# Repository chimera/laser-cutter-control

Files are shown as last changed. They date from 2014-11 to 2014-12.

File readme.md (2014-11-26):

# Chimera Laser Cutter Control

**Responsible Adult**: [Randy Hall](https://github.com/randybuildsthings)

This Chimera project provides the project (circuit board, bill of materials, etc.) to provide a Mach3/LinuxCNC capable controller board to drive the laser + the stepper motors that position the cutting beam.

This project borrows *heavily* (read: hours of looking over a PDF schematic) of the very excellent but out-of-stock Laser Cutter Converter board that Chris Jones of [Chris' Circuits](http://www.chriscircuits.com) successfully made and then sold out of repeatedly thanks to Hack-A-Day in 2013.

Well, it's almost 2015 and he doesn't seem to be making it any more. Enter the Chimera!

## Ew, EAGLE CAD

Yeah, it's EAGLE CAD. This design works entirely in their free tier, using just two layers and within the size constraints. We might consider moving it to KiCAD or another PCB layout tool, but for now, it's this.

This project was built from scratch using EAGLE CAD 7. We don't expect that it will work on previous version of the program.

## But, what do I do with this?

Ultimately, we will provide packaged and tagged releases of the Gerber and Excellon files for a given revision. Then you can take those files to your favorite PCB fab and get them made.

For now, you can load up whatever version of EAGLE CAD you can find, and open the `.SCH` and `.BRD` files into the software. Behold! The masterpiece. Now you can use the CAM batch tool to create the Gerber and Excellon files.

Step three... PROFIT!

## Warranty

*There is none.*

If you build and use this board and it burns down your laser cutter, your house, your RV, your office building, or the whole neighborhood, **it's on you bro.** If you don't accept this, then don't use this design. Otherwise, experiment wisely and always have a fire extinguisher handy. And an emergency power shutoff wouldn't hurt either.

The good news is we've now open sourced it, so knock yourself out! (*Note: any reference to knocking oneself out is said here only in jest, and neither Chimera Art Space or the author take any responsibility for anyone who actually takes the imperative literally, thereby effecting blunt force trauma on themselves causing loss of consciousness. This message will self-destruct whenever we get around to editing the Markdown to remove it*)

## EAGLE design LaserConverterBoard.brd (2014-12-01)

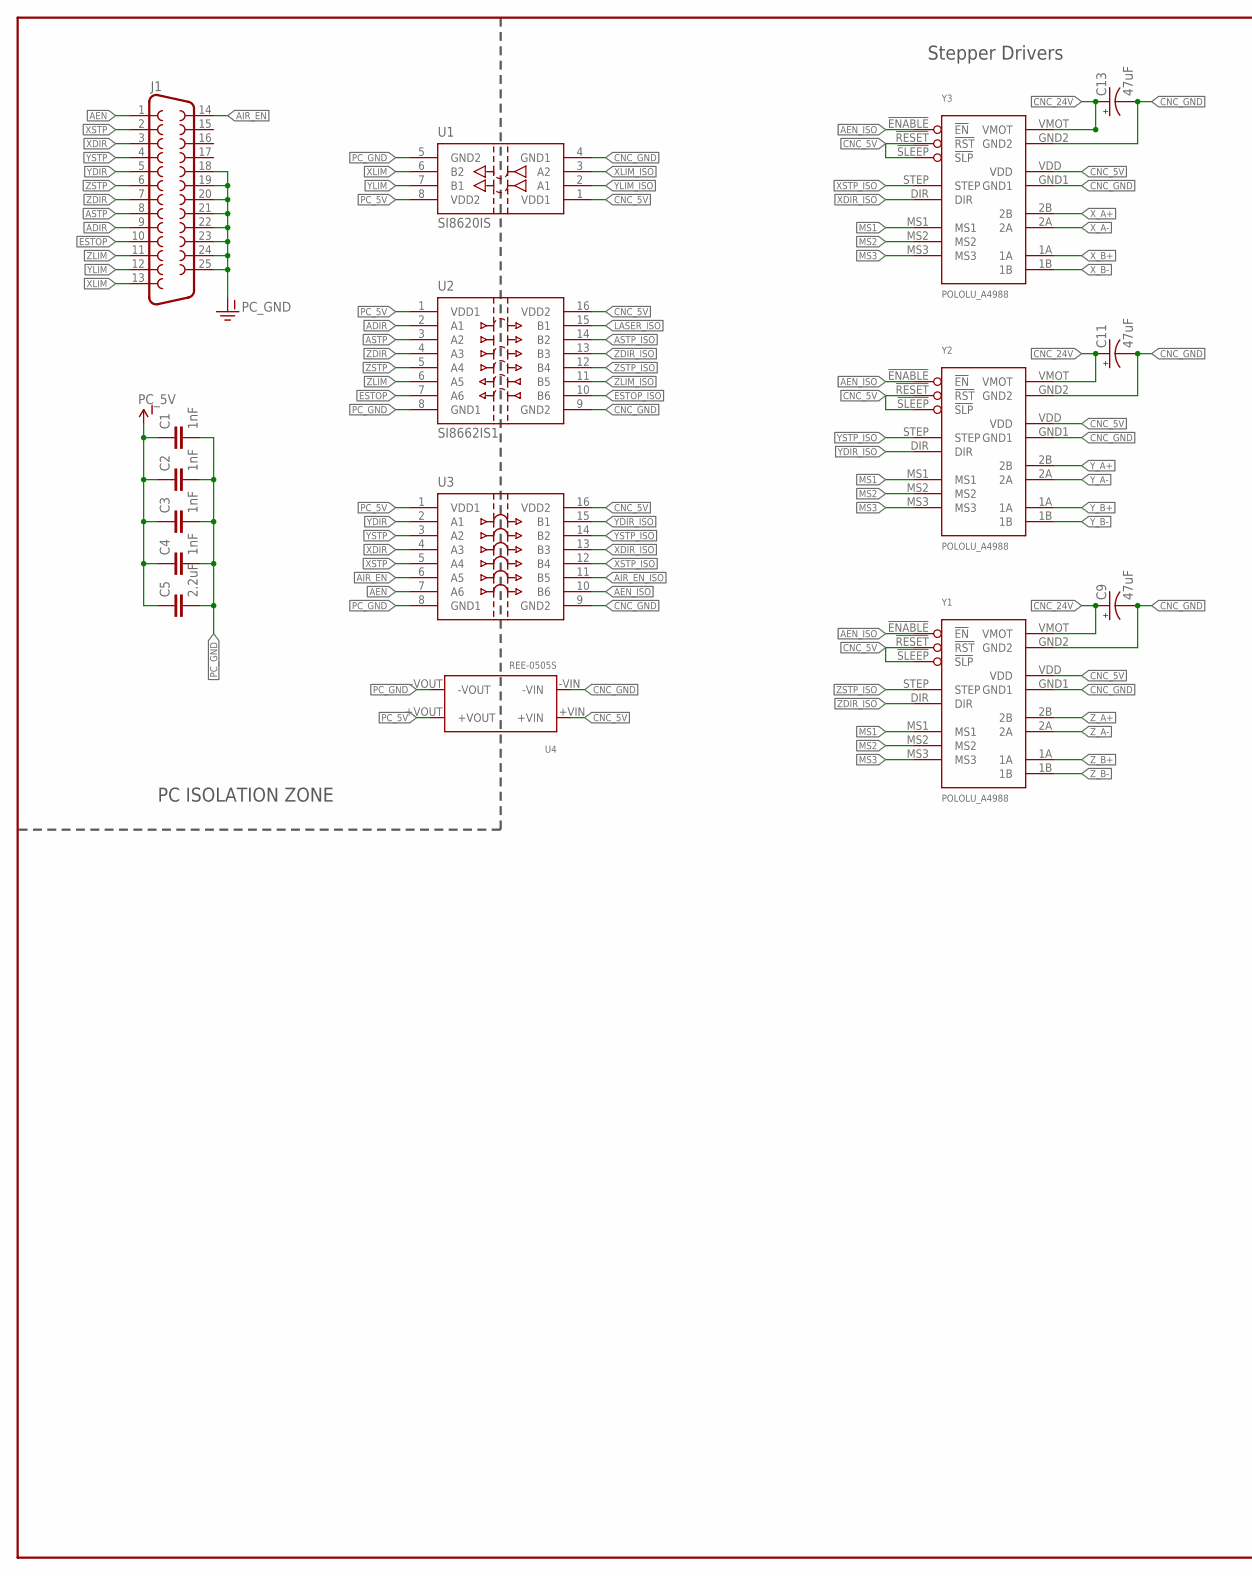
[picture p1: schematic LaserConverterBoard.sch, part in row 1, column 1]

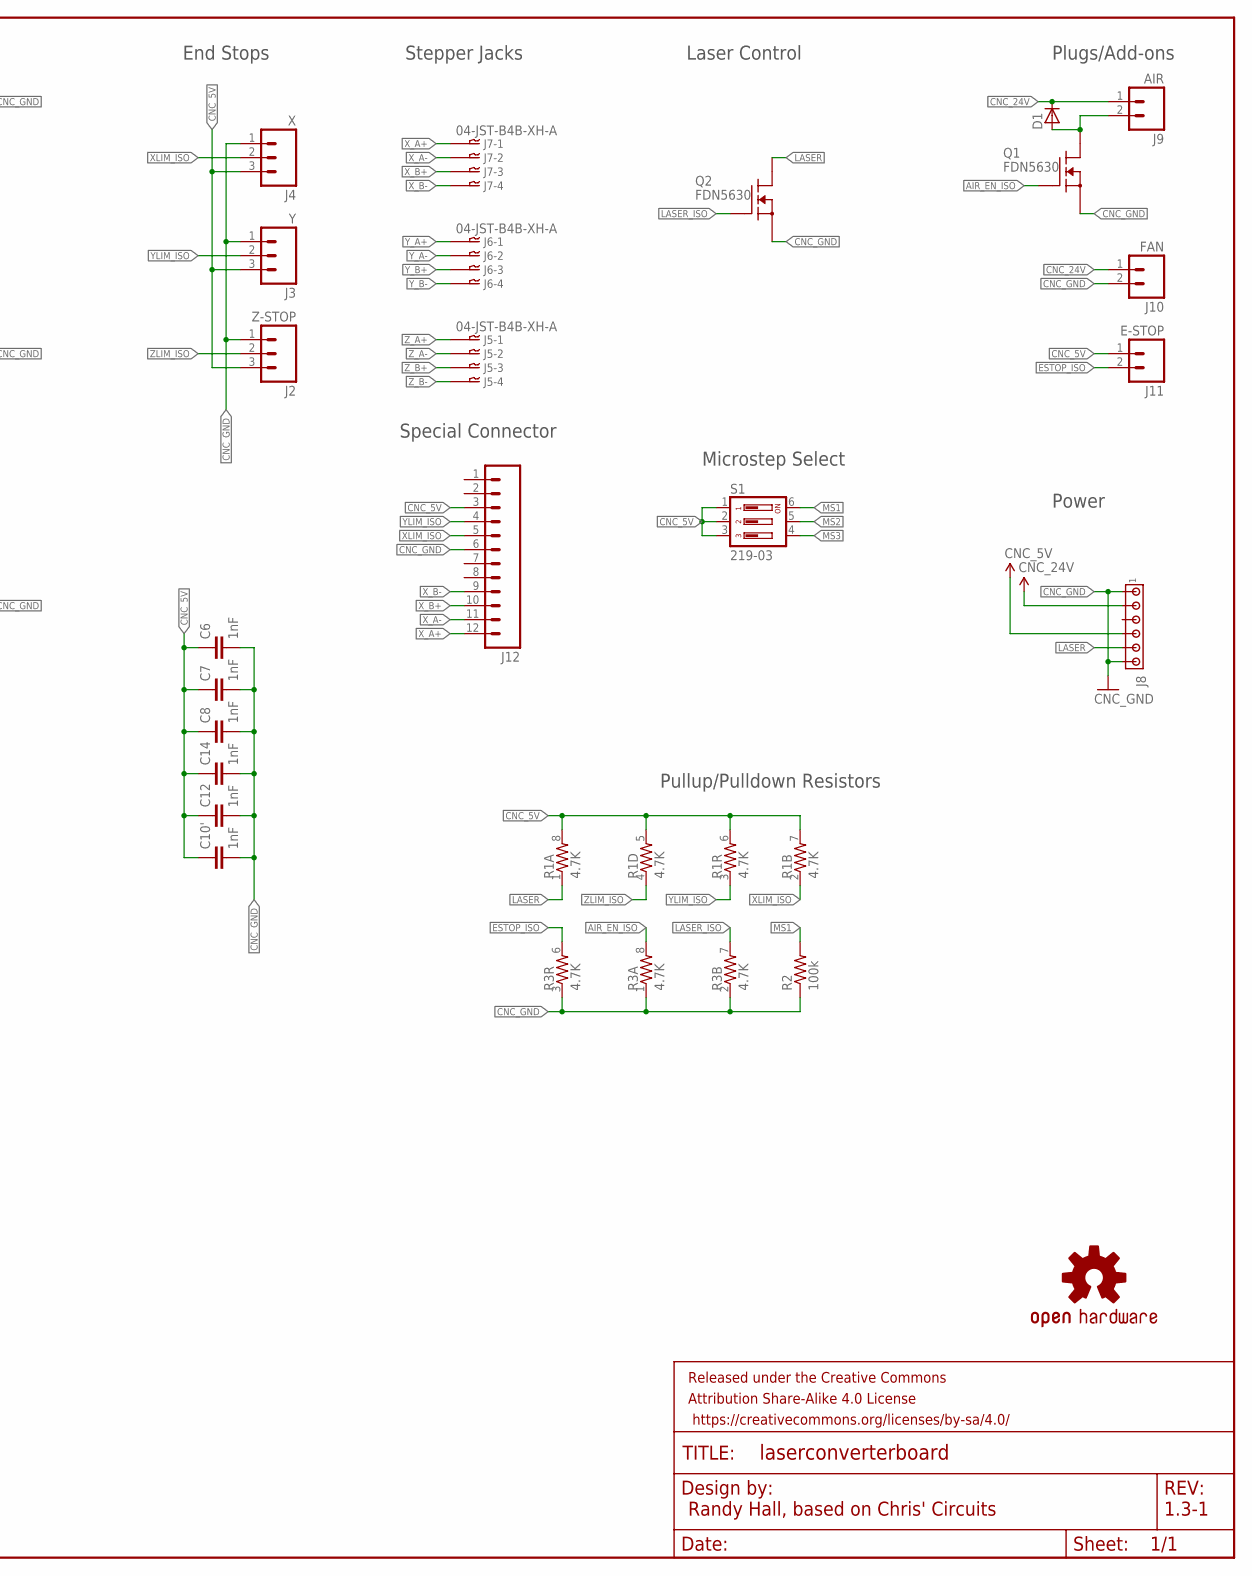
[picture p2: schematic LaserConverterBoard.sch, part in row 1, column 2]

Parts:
C1, C2, C3, C4, C6, C7, C8, C10', C12, C14: 1nF; 0603-CAP
C5: 2.2uF; 0603-CAP
C9, C11, C13: 47uF; PANASONIC_E
D1: D-SOD123; SOD123
FRAME1: FRAME-LEDGER; CREATIVE_COMMONS
J1: F25HP
J2: Z-STOP; 1X03
J3: Y; 1X03
J4: X; 1X03
J5, J6, J7: 04-JST-B4B-XH-A; B4B-XH
J8: MTA06-156; 1X6MTA
J9: AIR; 1X02
J10: FAN; 1X02
J11: E-STOP; 1X02
J12: M12; 12P
LOGO1: OSHW-LOGOS; OSHW-LOGO-S
Q1, Q2: FDN5630; SOT23
R1, R3: 4.7K; 0603-ARV
R2: 100k; 0603-RES
S1: 219-03; CTS-219-03
U1: SI8620IS; SO08
U2: SI8662IS1; SO16
U3: SI8460IS1; SO16
U4: REE-0505S; SIP7
Y1, Y2, Y3: POLOLU_A4988; POLOLU_STEPPER_DRIVER

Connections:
ADIR: J1.9, U2.2 (A1)
AEN: J1.1, U3.7 (A6)
AEN_ISO: U3.10 (B6), Y1.!ENABLE (!EN), Y2.!ENABLE (!EN), Y3.!ENABLE (!EN)
AIR_EN: J1.14, U3.6 (A5)
AIR_EN_ISO: Q1.1 (G), R3.8 (2), U3.11 (B5)
ASTP: J1.8, U2.3 (A2)
ASTP_ISO: U2.14 (B2)
CNC_5V: C6.1, C7.1, C8.1, C10'.1, C12.1, C14.1, J2.3, J3.3, J4.3, J8.4, J11.1, J12.3, R1.5 (2), R1.6 (2), R1.7 (2), R1.8 (2), S1.1, S1.2, S1.3, U1.1 (VDD1), U2.16 (VDD2), U3.16 (VDD2), U4.+VIN, Y1.!RESET (!RST), Y1.!SLEEP (!SLP), Y1.VDD, Y2.!RESET (!RST), Y2.!SLEEP (!SLP), Y2.VDD, Y3.!RESET (!RST), Y3.!SLEEP (!SLP), Y3.VDD
CNC_24V: C9.+, C11.+, C13.+, D1.1 (C), J8.2, J9.1, J10.1, Y1.VMOT, Y2.VMOT, Y3.VMOT
CNC_GND: C6.2, C7.2, C8.2, C9.-, C10'.2, C11.-, C12.2, C13.-, C14.2, J2.1, J3.1, J4.1, J8.1, J8.6, J10.2, J12.6, Q1.2 (S), Q2.2 (S), R2.1, R3.1, R3.2 (1), R3.3 (1), U1.4 (GND1), U2.9 (GND2), U3.9 (GND2), U4.-VIN, Y1.GND1, Y1.GND2, Y2.GND1, Y2.GND2, Y3.GND1, Y3.GND2
ESTOP: J1.10, U2.7 (A6)
ESTOP_ISO: J11.2, R3.6 (2), U2.10 (B6)
LASER: J8.5, Q2.3 (D), R1.1
LASER_ISO: Q2.1 (G), R3.7 (2), U2.15 (B1)
MS1: R2.2, S1.6, Y1.MS1, Y2.MS1, Y3.MS1
MS2: S1.5, Y1.MS2, Y2.MS2, Y3.MS2
MS3: S1.4, Y1.MS3, Y2.MS3, Y3.MS3
unnamed: D1.2 (A), J9.2, Q1.3 (D)
PC_5V: C1.1, C2.1, C3.1, C4.1, C5.1, U1.8 (VDD2), U2.1 (VDD1), U3.1 (VDD1), U4.+VOUT
PC_GND: C1.2, C2.2, C3.2, C4.2, C5.2, J1.18, J1.19, J1.20, J1.21, J1.22, J1.23, J1.24, J1.25, U1.5 (GND2), U2.8 (GND1), U3.8 (GND1), U4.-VOUT
XDIR: J1.3, U3.4 (A3)
XDIR_ISO: U3.13 (B3), Y3.DIR
XLIM: J1.13, U1.6 (B2)
XLIM_ISO: J4.2, J12.5, R1.2 (1), U1.3 (A2)
XSTP: J1.2, U3.5 (A4)
XSTP_ISO: U3.12 (B4), Y3.STEP
X_A+: J7.P$1, J12.12, Y3.2B
X_A-: J7.P$2, J12.11, Y3.2A
X_B+: J7.P$3, J12.10, Y3.1A
X_B-: J7.P$4, J12.9, Y3.1B
YDIR: J1.5, U3.2 (A1)
YDIR_ISO: U3.15 (B1), Y2.DIR
YLIM: J1.12, U1.7 (B1)
YLIM_ISO: J3.2, J12.4, R1.3 (1), U1.2 (A1)
YSTP: J1.4, U3.3 (A2)
YSTP_ISO: U3.14 (B2), Y2.STEP
Y_A+: J6.P$1, Y2.2B
Y_A-: J6.P$2, Y2.2A
Y_B+: J6.P$3, Y2.1A
Y_B-: J6.P$4, Y2.1B
ZDIR: J1.7, U2.4 (A3)
ZDIR_ISO: U2.13 (B3), Y1.DIR
ZLIM: J1.11, U2.6 (A5)
ZLIM_ISO: J2.2, R1.4 (1), U2.11 (B5)
ZSTP: J1.6, U2.5 (A4)
ZSTP_ISO: U2.12 (B4), Y1.STEP
Z_A+: J5.P$1, Y1.2B
Z_A-: J5.P$2, Y1.2A
Z_B+: J5.P$3, Y1.1A
Z_B-: J5.P$4, Y1.1B

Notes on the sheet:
Randy Hall, based on Chris' Circuits
1.3-1
PC ISOLATION ZONE
Pullup/Pulldown Resistors
Stepper Drivers
Plugs/Add-ons
Power
Microstep Select
End Stops
Stepper Jacks
Laser Control
Special Connector

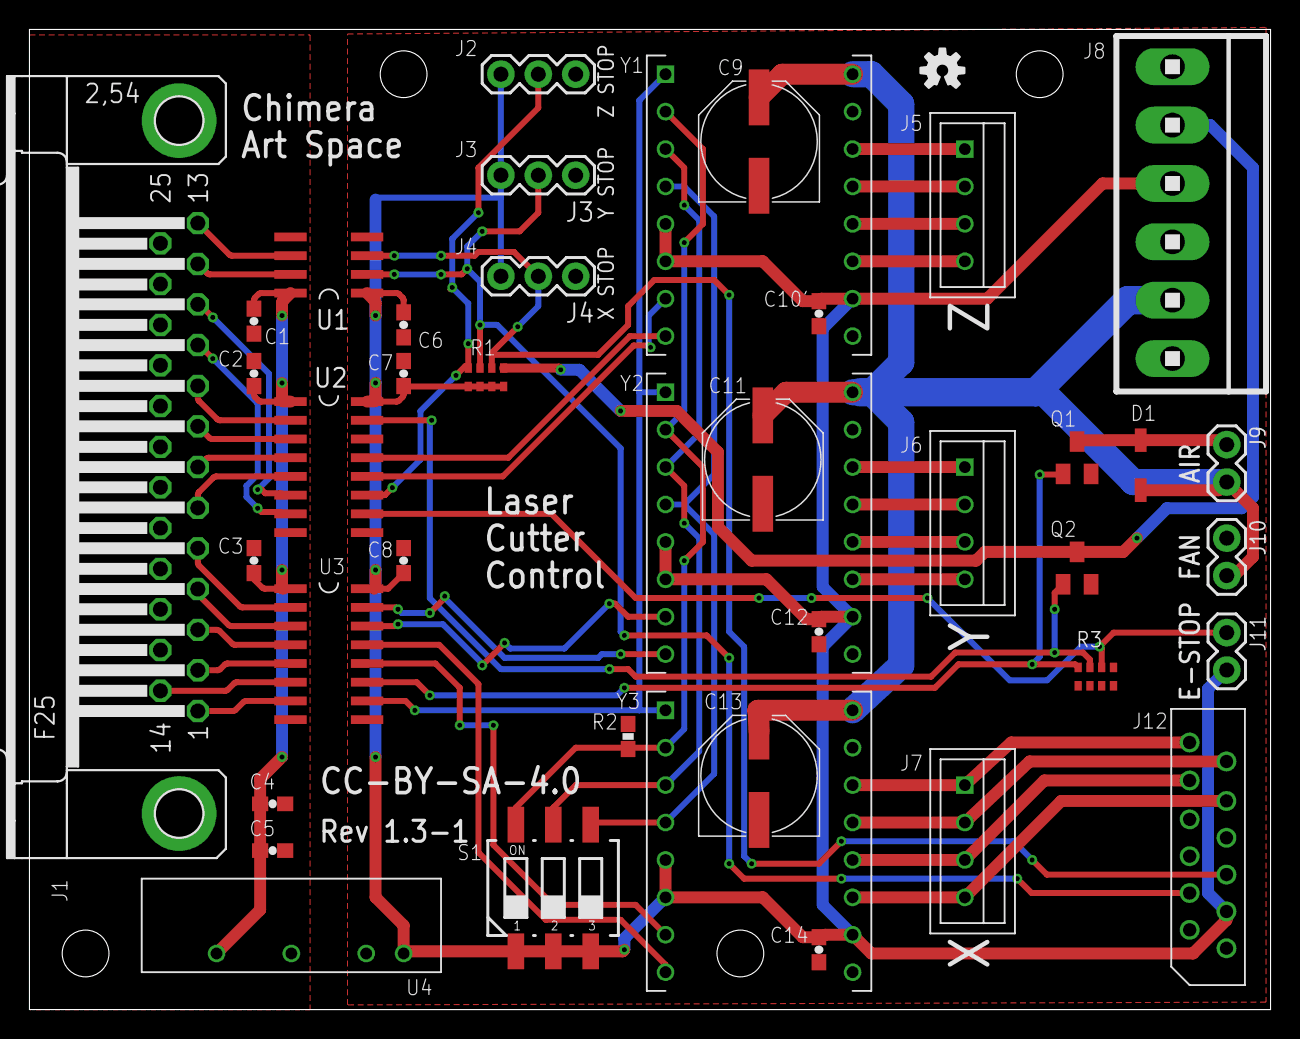
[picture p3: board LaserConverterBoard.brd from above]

Board: 2 copper layers, 84.3 x 66.5 mm, 42 parts (0 on the bottom side), 49 nets.

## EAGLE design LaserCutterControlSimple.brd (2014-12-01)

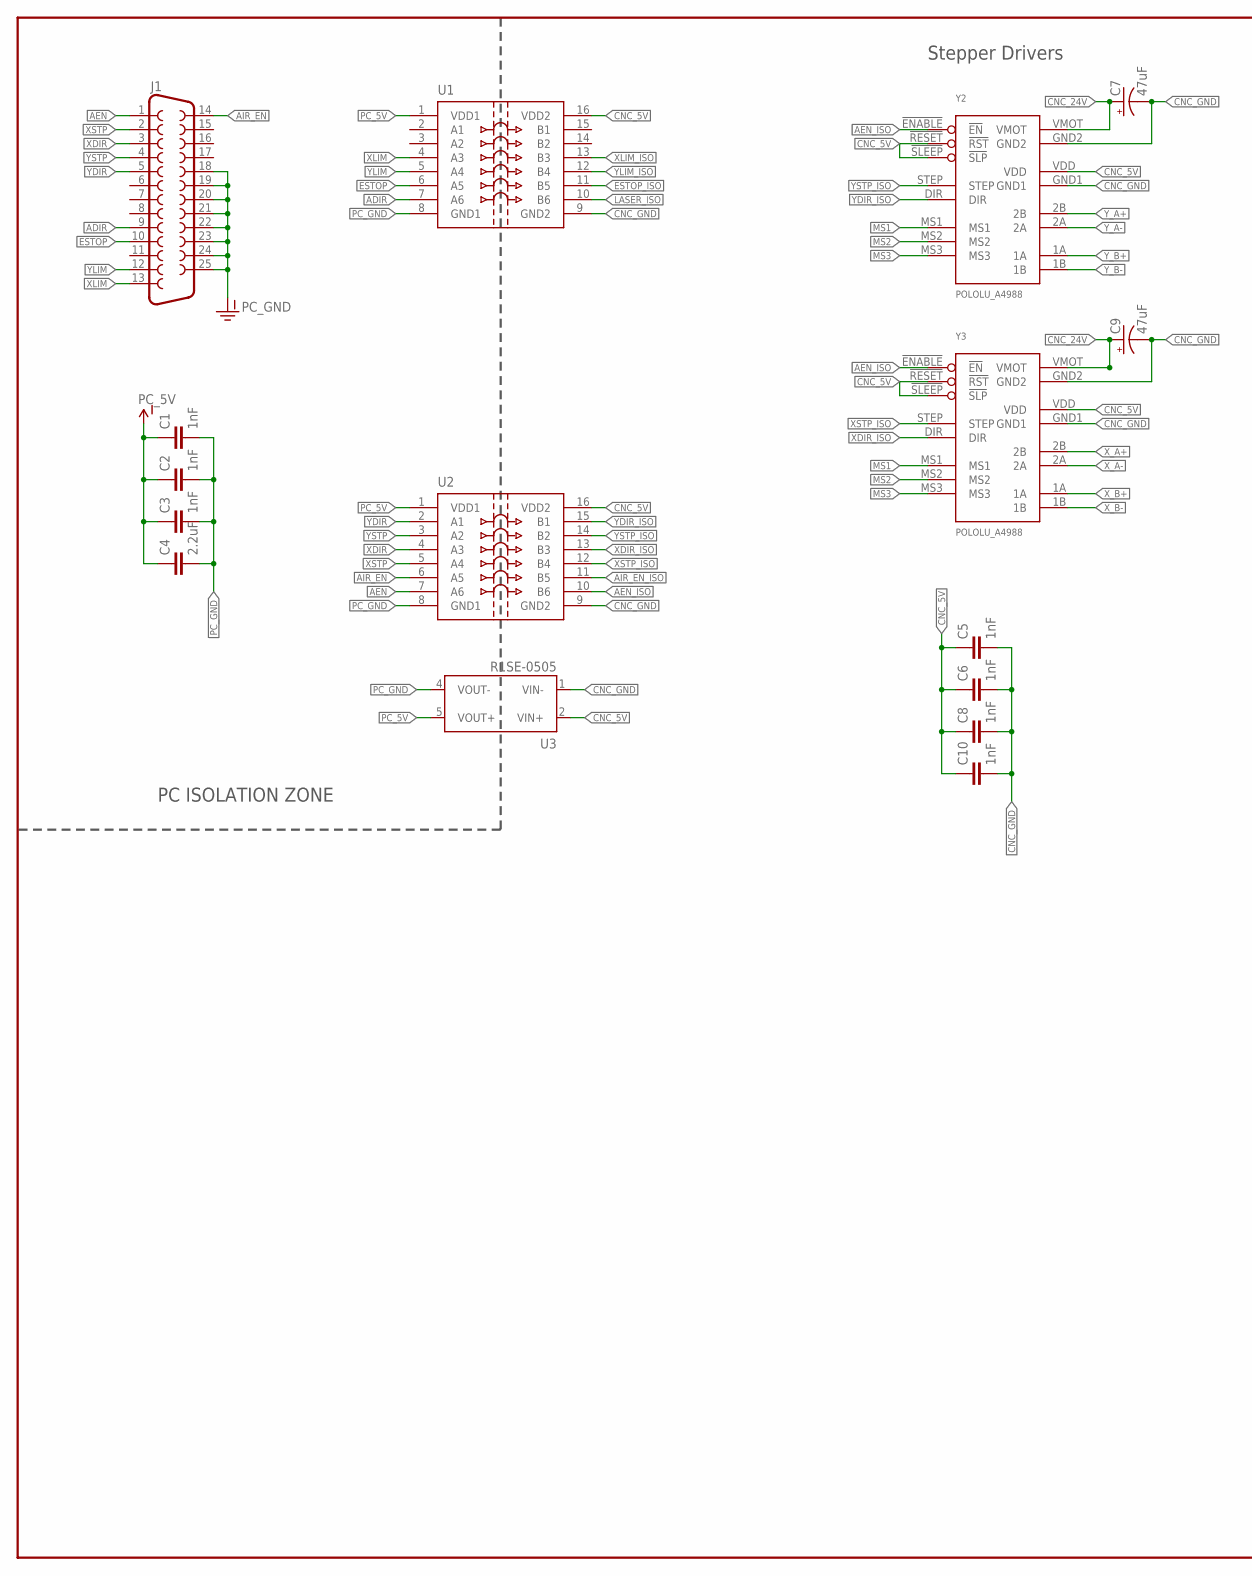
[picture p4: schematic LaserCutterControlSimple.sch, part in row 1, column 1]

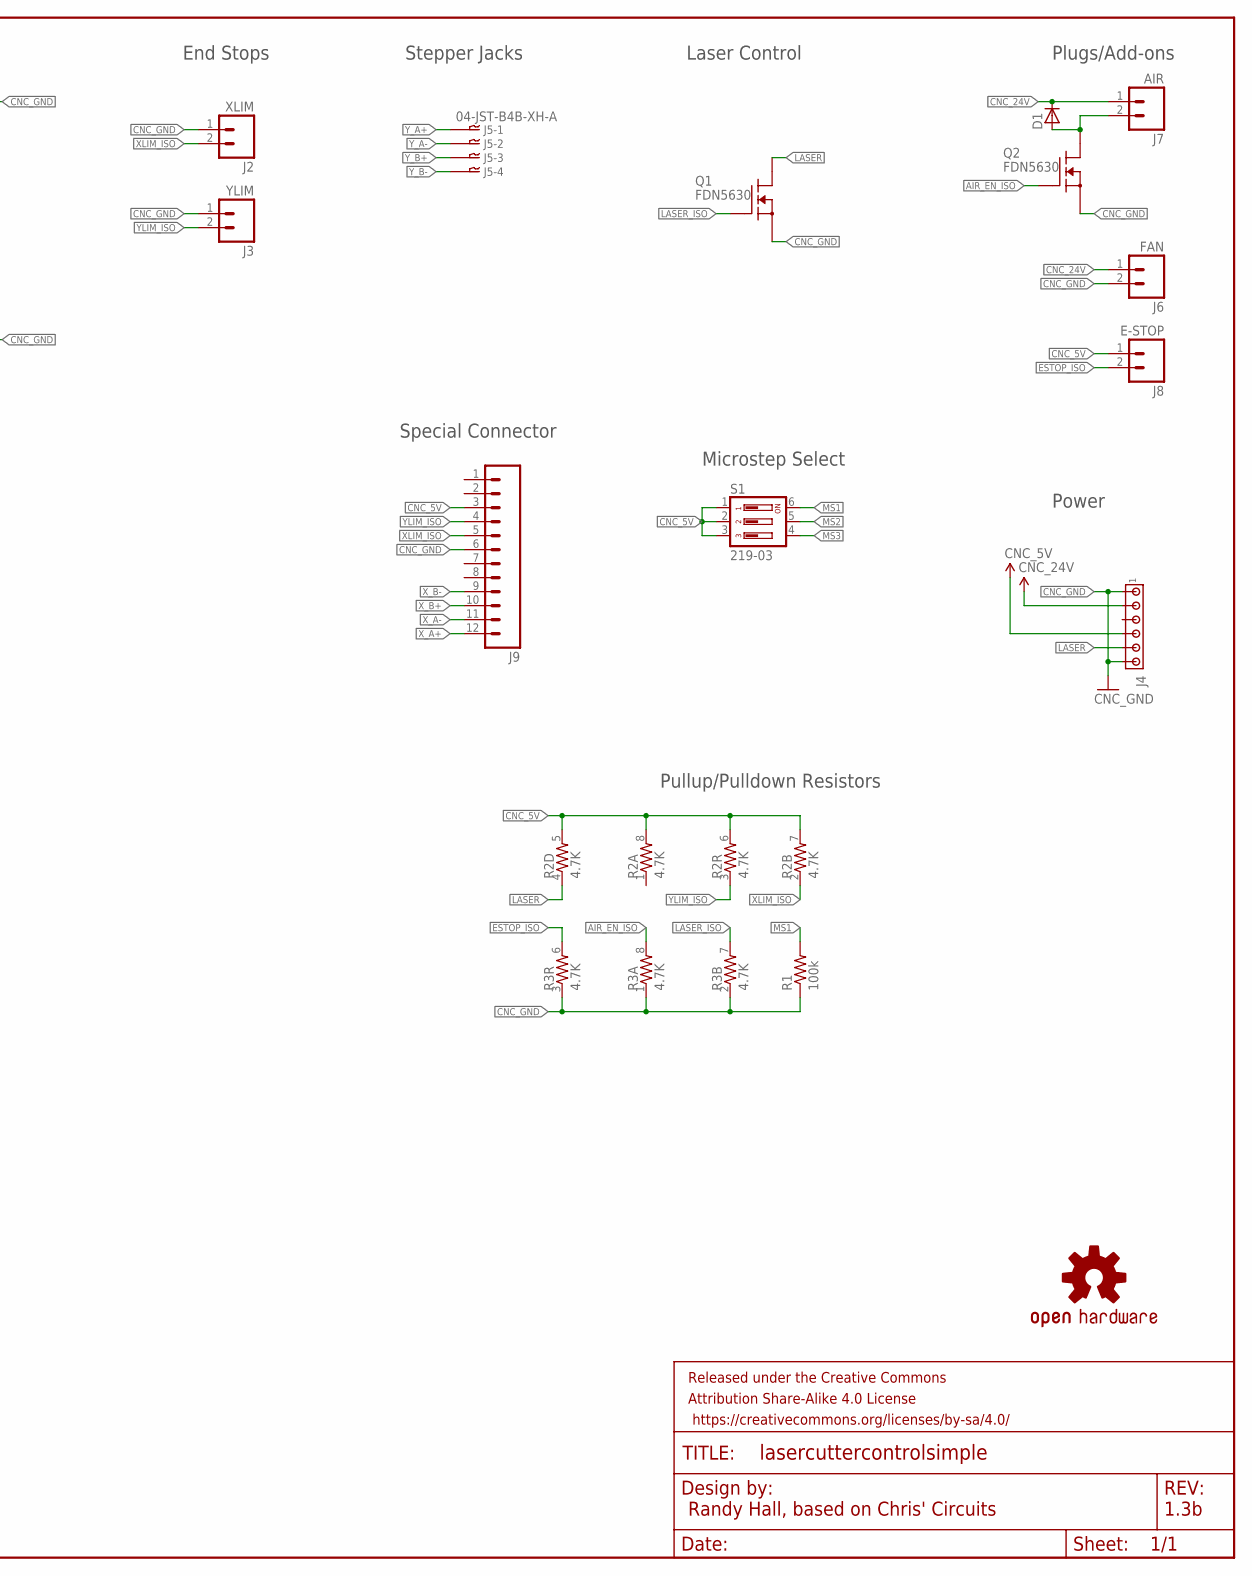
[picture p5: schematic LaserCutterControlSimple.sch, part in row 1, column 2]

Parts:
C1, C2, C3, C5, C6, C8, C10: 1nF; 0603-CAP
C4: 2.2uF; 0603-CAP
C7, C9: 47uF; PANASONIC_E
D1: D-SOD123; SOD123
FRAME1: FRAME-LEDGER; CREATIVE_COMMONS
J1: F25HP
J2: XLIM; 1X02
J3: YLIM; 1X02
J4: MTA06-156; 1X6MTA
J5: 04-JST-B4B-XH-A; B4B-XH
J6: FAN; 1X02
J7: AIR; 1X02
J8: E-STOP; 1X02
J9: M12; 12P
LOGO1: OSHW-LOGOM; OSHW-LOGO-M
Q1, Q2: FDN5630; SOT23
R1: 100k; 0603-RES
R2, R3: 4.7K; 0603-ARV
S1: 219-03; CTS-219-03
U1, U2: SI8460IS1; SO16
U3: R1SE-0505; SMD5
Y2, Y3: POLOLU_A4988; POLOLU_STEPPER_DRIVER

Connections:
ADIR: J1.9, U1.7 (A6)
AEN: J1.1, U2.7 (A6)
AEN_ISO: U2.10 (B6), Y2.!ENABLE (!EN), Y3.!ENABLE (!EN)
AIR_EN: J1.14, U2.6 (A5)
AIR_EN_ISO: Q2.1 (G), R3.8 (2), U2.11 (B5)
CNC_5V: C5.1, C6.1, C8.1, C10.1, J4.4, J8.1, J9.3, R2.5 (2), R2.6 (2), R2.7 (2), R2.8 (2), S1.1, S1.2, S1.3, U1.16 (VDD2), U2.16 (VDD2), U3.2 (VIN+), Y2.!RESET (!RST), Y2.!SLEEP (!SLP), Y2.VDD, Y3.!RESET (!RST), Y3.!SLEEP (!SLP), Y3.VDD
CNC_24V: C7.+, C9.+, D1.1 (C), J4.2, J6.1, J7.1, Y2.VMOT, Y3.VMOT
CNC_GND: C5.2, C6.2, C7.-, C8.2, C9.-, C10.2, J2.1, J3.1, J4.1, J4.6, J6.2, J9.6, Q1.2 (S), Q2.2 (S), R1.1, R3.1, R3.2 (1), R3.3 (1), U1.9 (GND2), U2.9 (GND2), U3.1 (VIN-), Y2.GND1, Y2.GND2, Y3.GND1, Y3.GND2
ESTOP: J1.10, U1.6 (A5)
ESTOP_ISO: J8.2, R3.6 (2), U1.11 (B5)
LASER: J4.5, Q1.3 (D), R2.4 (1)
LASER_ISO: Q1.1 (G), R3.7 (2), U1.10 (B6)
MS1: R1.2, S1.6, Y2.MS1, Y3.MS1
MS2: S1.5, Y2.MS2, Y3.MS2
MS3: S1.4, Y2.MS3, Y3.MS3
unnamed: D1.2 (A), J7.2, Q2.3 (D)
PC_5V: C1.1, C2.1, C3.1, C4.1, U1.1 (VDD1), U2.1 (VDD1), U3.5 (VOUT+)
PC_GND: C1.2, C2.2, C3.2, C4.2, J1.18, J1.19, J1.20, J1.21, J1.22, J1.23, J1.24, J1.25, U1.8 (GND1), U2.8 (GND1), U3.4 (VOUT-)
XDIR: J1.3, U2.4 (A3)
XDIR_ISO: U2.13 (B3), Y3.DIR
XLIM: J1.13, U1.4 (A3)
XLIM_ISO: J2.2, J9.5, R2.2 (1), U1.13 (B3)
XSTP: J1.2, U2.5 (A4)
XSTP_ISO: U2.12 (B4), Y3.STEP
X_A+: J9.12, Y3.2B
X_A-: J9.11, Y3.2A
X_B+: J9.10, Y3.1A
X_B-: J9.9, Y3.1B
YDIR: J1.5, U2.2 (A1)
YDIR_ISO: U2.15 (B1), Y2.DIR
YLIM: J1.12, U1.5 (A4)
YLIM_ISO: J3.2, J9.4, R2.3 (1), U1.12 (B4)
YSTP: J1.4, U2.3 (A2)
YSTP_ISO: U2.14 (B2), Y2.STEP
Y_A+: J5.P$1, Y2.2B
Y_A-: J5.P$2, Y2.2A
Y_B+: J5.P$3, Y2.1A
Y_B-: J5.P$4, Y2.1B

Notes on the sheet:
Randy Hall, based on Chris' Circuits
1.3b
PC ISOLATION ZONE
Pullup/Pulldown Resistors
Stepper Drivers
Plugs/Add-ons
Power
Microstep Select
End Stops
Stepper Jacks
Laser Control
Special Connector

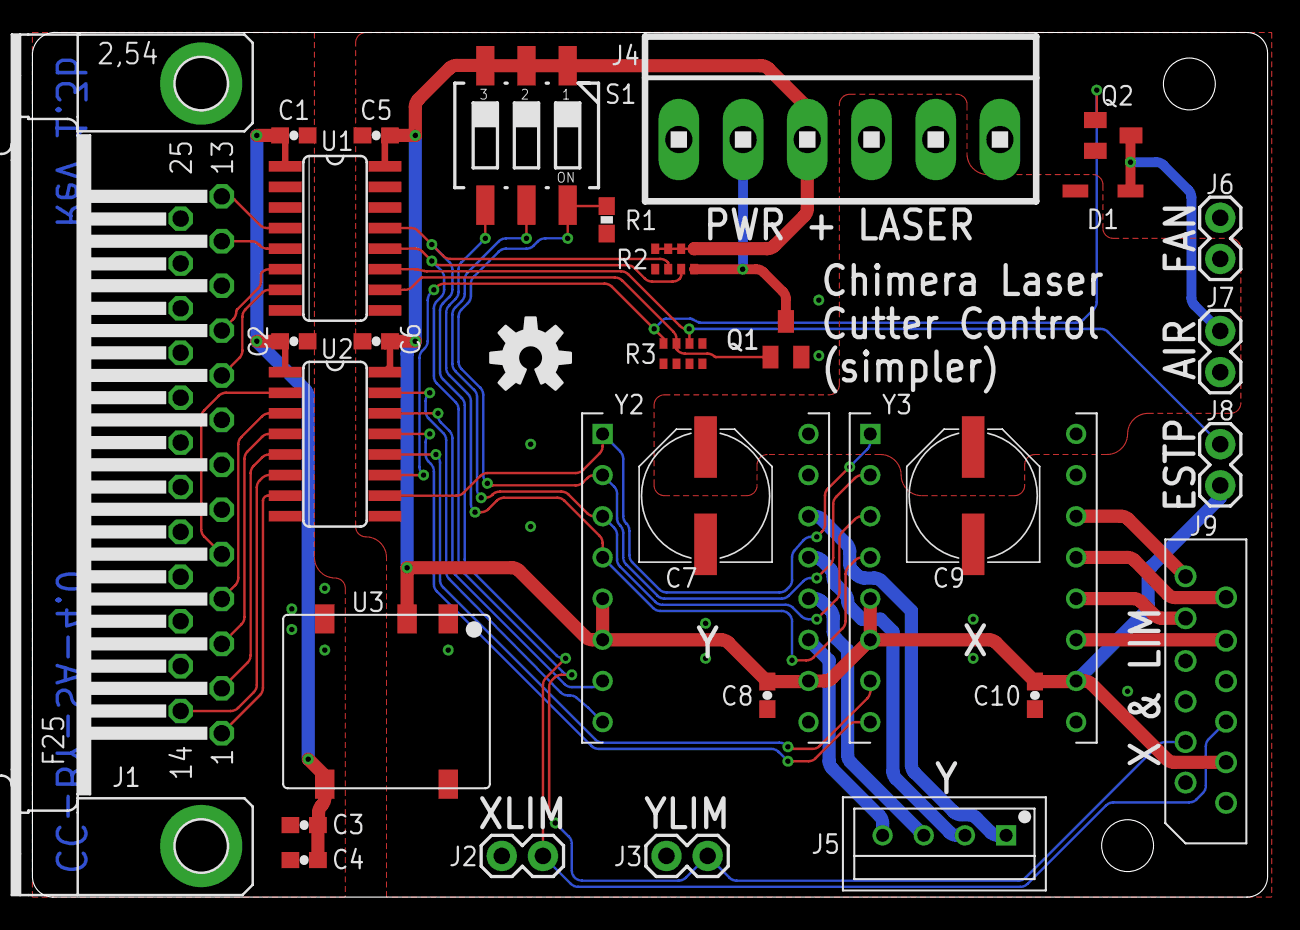
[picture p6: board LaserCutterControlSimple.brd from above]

Board: 2 copper layers, 76.2 x 53.3 mm, 33 parts (0 on the bottom side), 38 nets.

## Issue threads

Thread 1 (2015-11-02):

Do you have a BOM?

spaelectronics, 2015-11-02:
Is there any way I could get a BOM for this?

danawoodman, 2015-11-03:
@randybuildsthings is the mastermind behind this, maybe he can help

jegb, 2015-12-13:
Last summer I designed similar board, but with an addition to use grbl shield to plug an arduino under it (in case that you want to avoid PC parallel port). Not sure how much traction this will get with Smoothie, LaOS, and the marlin/mega/ramps combo operating in same space. I also went with multiple isolators on same chip, bom and assembly costs could be competitive compared to these options though.

randybuildsthings, 2016-02-19:
Sorry guys, been off fighting other battles away from Github.

There is no BOM available at this time. I would have to crack open the EAGLE CAD files and have a look. It may very well be that I've partially specified the parts inside of EAGLE, and a BOM could be constructed from that. Let's just say that I'm not in as big a hurry to do this as I was a year ago. Sorry I can't be more help here.

randybuildsthings, 2016-02-19:
And @jegb this project clearly didn't get traction with Smoothie, I had several conversations with the devs for Smoothie and was vying for a board to use for development of the laser cutter. As I said, I've moved onto other things at the moment and don't have a timetable for developing this further.

Closed 2016-02-19.

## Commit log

2014-11-26 Initial commit to the repo
    [LaserConverterBoard.brd, LaserConverterBoard.sch]
2014-11-26 Hand routing of board 1.3 complete. Still needs silk screening done.
    [LaserConverterBoard.brd, LaserConverterBoard.sch]
2014-11-26 Silk screen done, could use a Chimera Logo on it, IMO
    [LaserConverterBoard.brd, LaserConverterBoard.sch]
2014-11-27 Added Silk Screen for name and CC/OSHW licensing
    [LaserConverterBoard.brd]
2014-11-27 Adding alternate, stripped-down version of the board. Fewer parts, smaller footprint, cheaper to fabricate.
    [LaserCutterControlSimple.brd, LaserCutterControlSimple.sch]
2014-11-30 Minor dumb change because it was very early in the morning when I finished the simplified board design. Silk screen and connector change to better match laser cutter connections.
    [LaserCutterControlSimple.brd, LaserCutterControlSimple.sch]
2014-11-30 More silkscreen and plug fixes to full-size board
    [LaserConverterBoard.brd, LaserConverterBoard.sch]
2014-12-01 More tweaks to 1.3-1 and 1.3b, some repositioning and swapping of parts for layout, now that I've seen what the inside of the laser cutter looks like. Added pinouts for X and Y limits to the simple b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
    [LaserConverterBoard.brd, LaserConverterBoard.sch, LaserCutterControlSimple.brd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]
2014-12-01 Okay, now the pins that need to feed back to the CNC controller actually can get there. What a mess. Bill of materials will now have three individual parts. I can see why Chris did it with nine Si842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
    [LaserConverterBoard.brd, LaserConverterBoard.sch]

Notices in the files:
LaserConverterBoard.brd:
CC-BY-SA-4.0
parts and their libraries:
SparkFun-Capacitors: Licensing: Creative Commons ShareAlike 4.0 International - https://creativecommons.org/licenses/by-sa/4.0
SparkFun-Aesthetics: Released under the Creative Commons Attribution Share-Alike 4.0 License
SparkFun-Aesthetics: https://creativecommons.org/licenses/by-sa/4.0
